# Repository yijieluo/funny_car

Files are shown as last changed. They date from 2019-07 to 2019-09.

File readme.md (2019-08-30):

### 2019/7/15

#### 引言
    1、这是用于rt-thread举办的智能战车DIY活动的一个项目.
    2、目标是设计一个两轮平衡小车，完成基本功能，平衡和遥控。如果有时间会增加树莓派做物体跟踪。   
    3、硬件搭建：采用大疆的m2006无刷电机搭配c610电调，采用6s航模锂电池供电（不加稳压模块），mcu选用stm32f407zgt6，imu模块选用gy-86，蓝牙hc-05作为遥控通信，选用us-100超声波模块用来避障。

#### 目前进度：
    1.已在正点原子探索者开发板上完成了：在rt-thread 4.0.0系统下，对两个电机的控制（基于can总线），读取gy-86的九轴数据（怀疑磁力计读数有问题，暂时姿态解算有问题），还有硬件定时器，软件定时器，LED控制等一下简单的功能。   
    2.pcb已经完成mcu最小系统，lm2576-5、asm1117-3.3稳压部分，can芯片tja1050电路，的设计。   
    3.电机支架和底板的机械图纸已设计好（同学帮忙设计的），已经送去加工了。

### 2019/8/28
#### 目前已基本完成要求功能，ps2遥控控制两轮平衡车较稳定的运行。

    1、硬件上，24v转5v，5转3.3v稳压电路，stm32f407zgt6最小系统与外围接口电路，pcb做了两版才成功。    
    2、软件上，完成了，姿态结算，数据滤波，串级pid 外环角度环，内环速度环，在线pid参数修改，串口配合山外调试助手在线看数据波形，ps2遥控控制等。

#### 还准备继续做的内容：
    1、减少一些全局变量的使用，用rtt的IPC来替代。    
    2、通过yaw角度或电机编码器，实现转向环 速度 的闭环控制。增加 前进 和 转向 的位置控制。（前面的都是速度控制）    
    3、增加树莓派做图像处理的一些工作。

#### [整理的博客](https://www.cnblogs.com/luoyijie/p/11433817.html)
#### [演示视频1](https://v.youku.com/v_show/id_XNDMzNzExODMyMA==.html) [演示视频2](https://v.youku.com/v_show/id_XNDMzNzExODMxNg==.html)

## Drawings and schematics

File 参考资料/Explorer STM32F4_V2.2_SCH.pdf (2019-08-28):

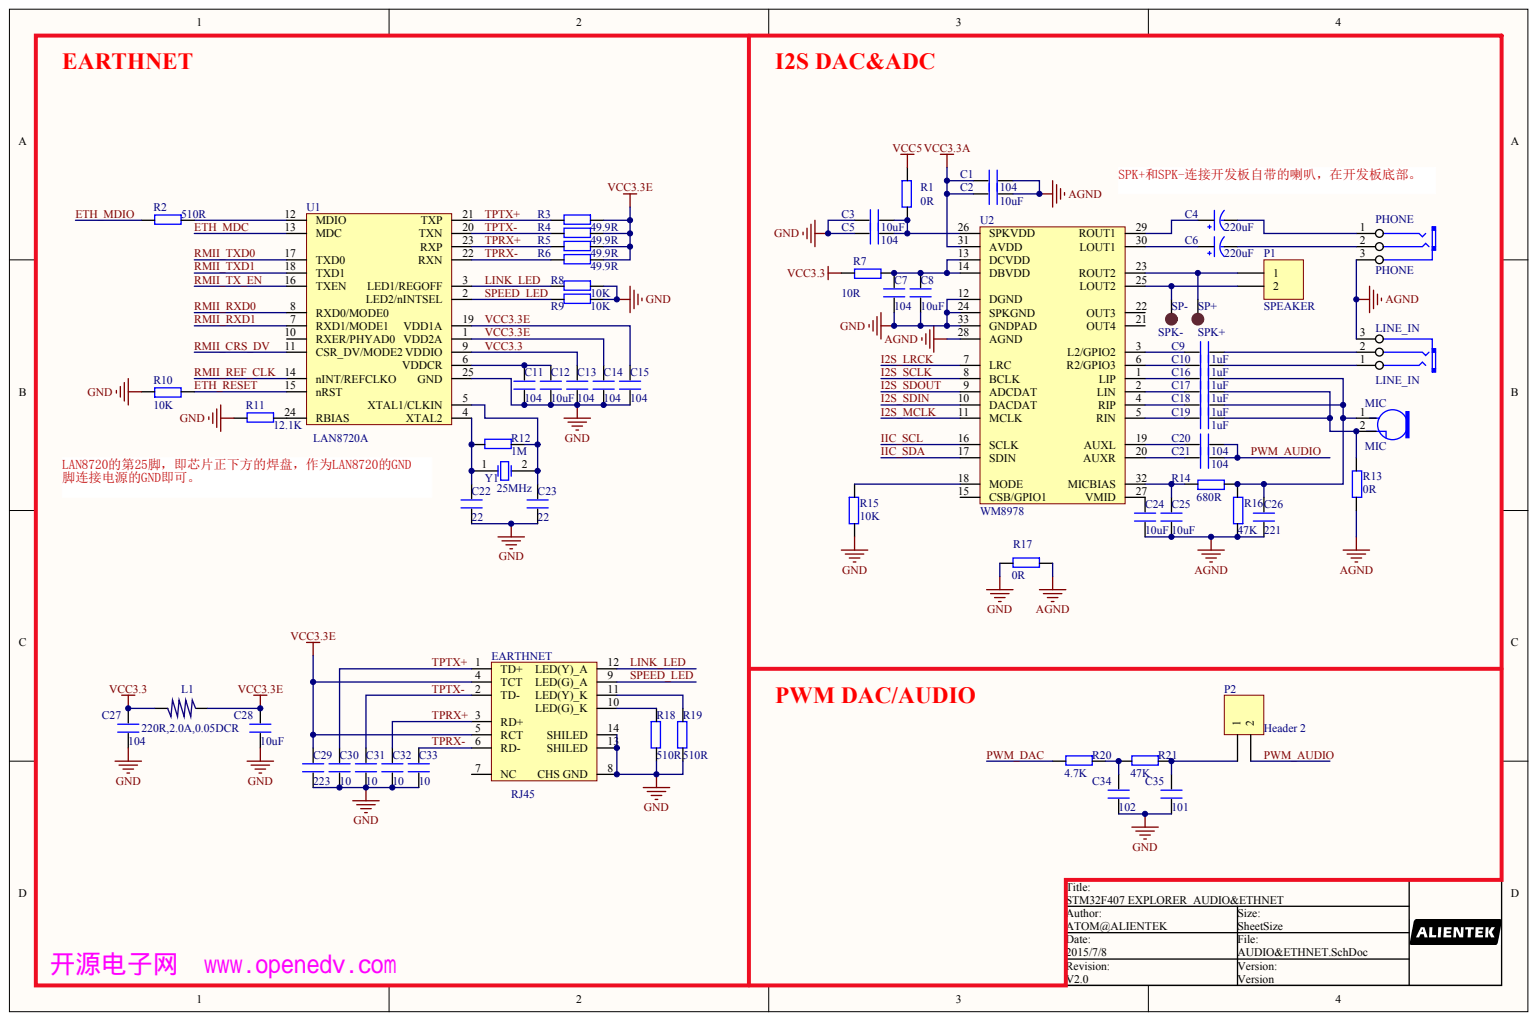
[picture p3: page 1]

SPK+和SPK-连接开发板自带的喇叭，在开发板底部。

TPTX- | | TD- 2

TPRX+ | | RD+ 3

RCT 5

Title: STM32F407 EXPLORER_AUDIO&ETHNET

Author: ATOM@ALIENTEK | Size: SheetSize

Date: 2015/7/8 | File: AUDIO&ETHNET.SchDoc

开源电子网 www.openedv.com

Revision: V2.0 | Version: Version

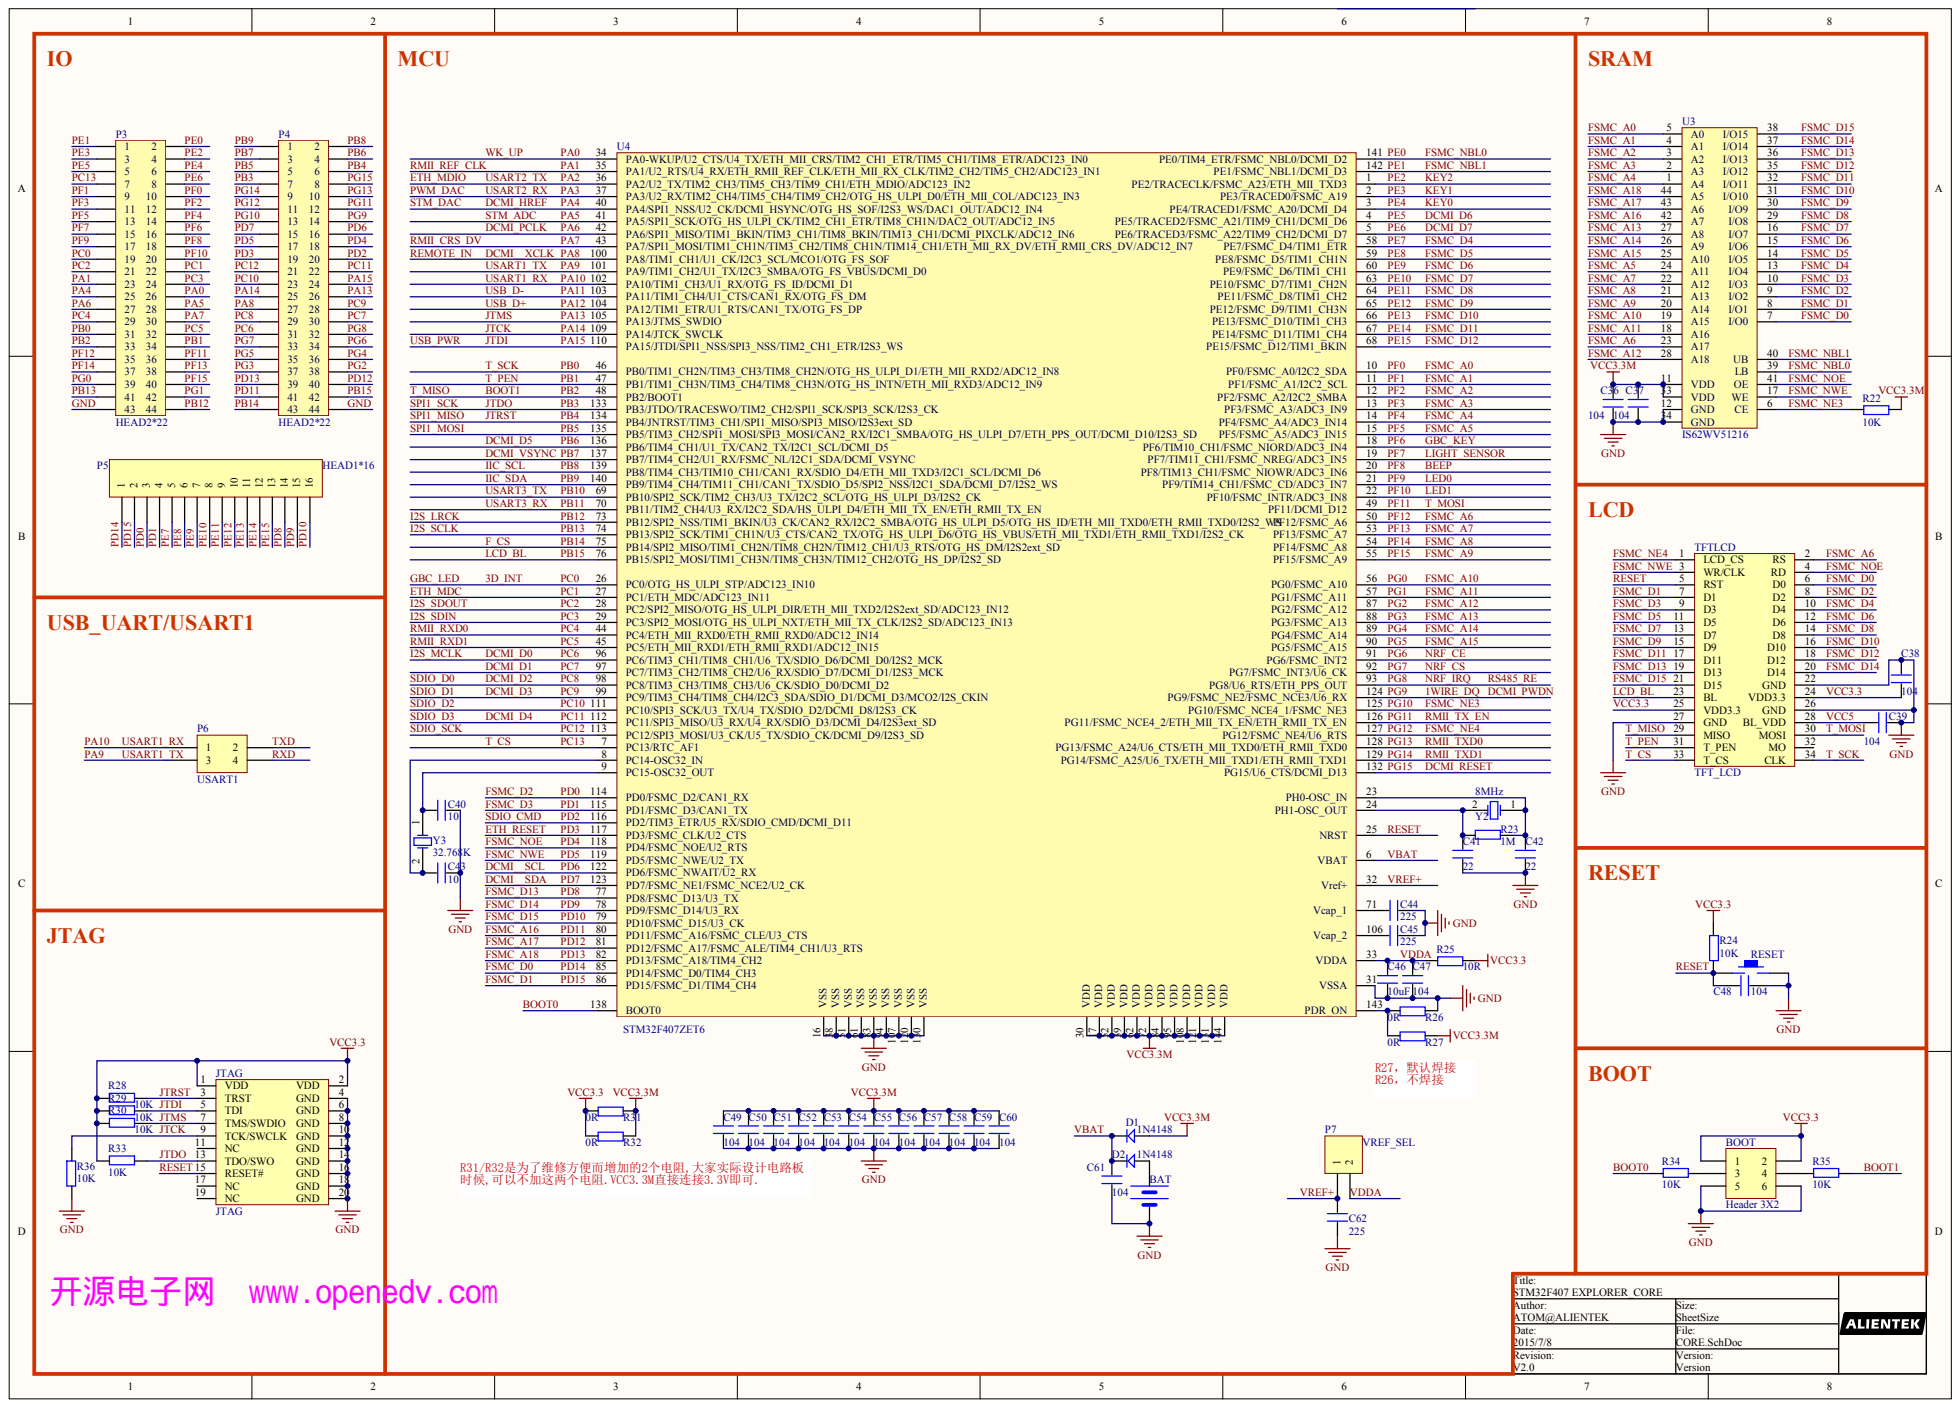
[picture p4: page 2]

开源电子网 www.openedv.com

Title: STM 32F407 EXPLORER_CORE

Author: ATOM @ALIENTEK | Size: SheetSize

Date: 2015/7/8 | File: CORE.SchDoc

Revisi on: V2.

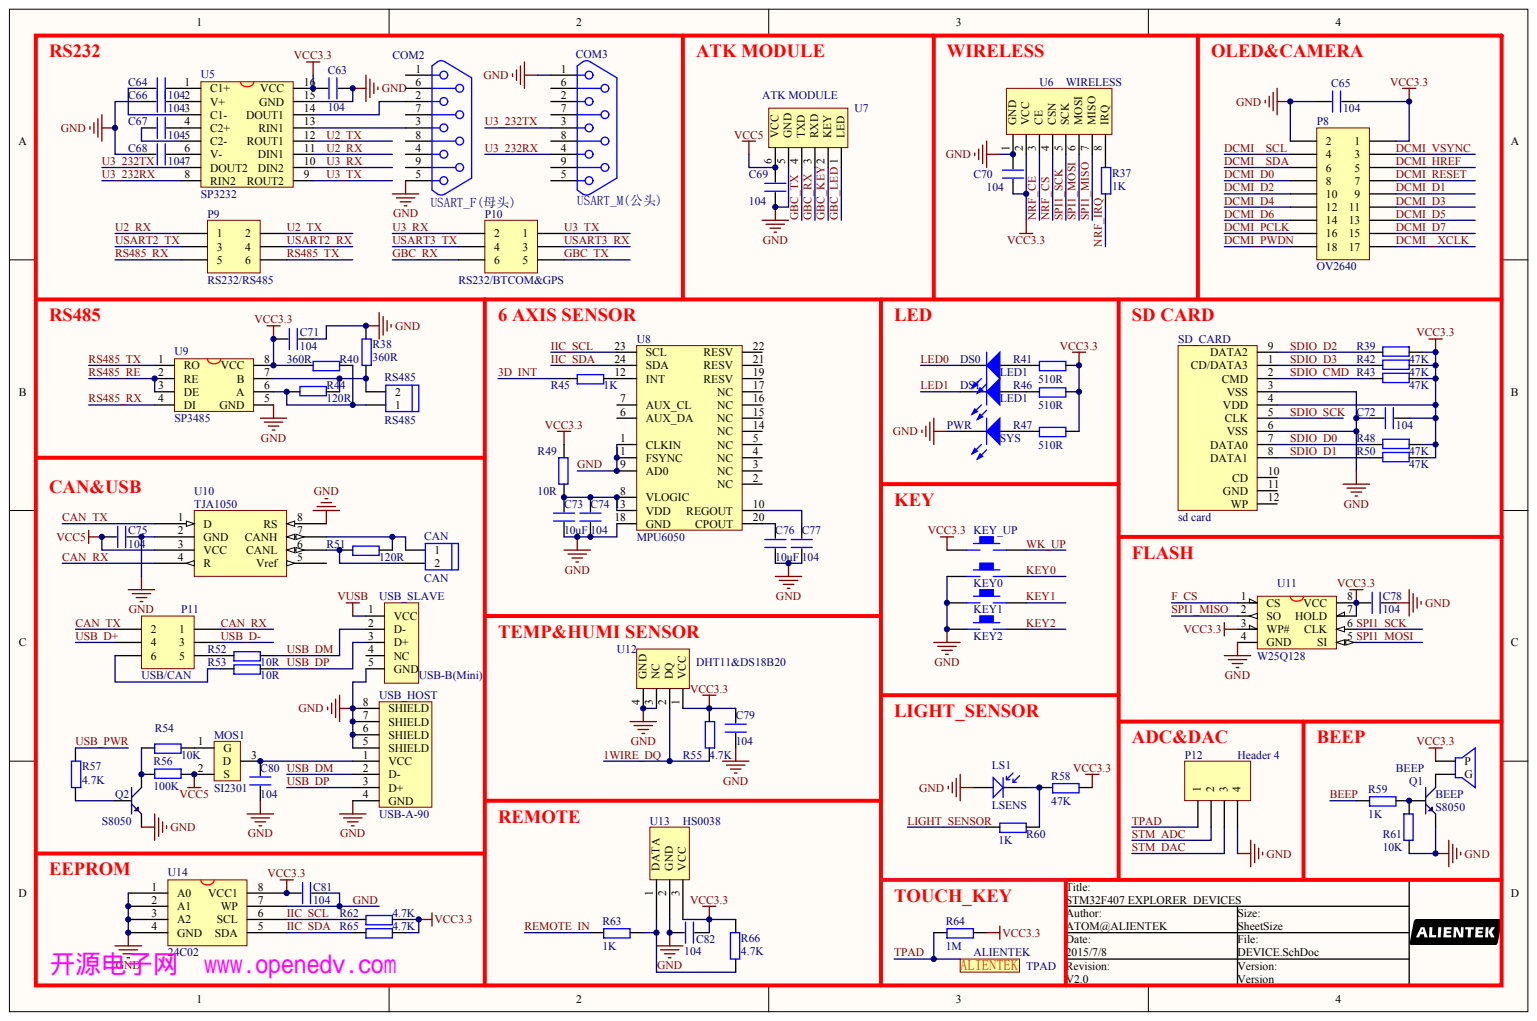
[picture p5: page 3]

LED 1 KEY 2 RXD 3 TXD 4

VCC 3

VCC 1 DQ 2 NC 3 GND 4

Author: ATOM@ALIENTEK | Size: SheetSize

Date: 2015/7/8 | File: DEVICE.SchDoc

开源电子网 www.openedv.com

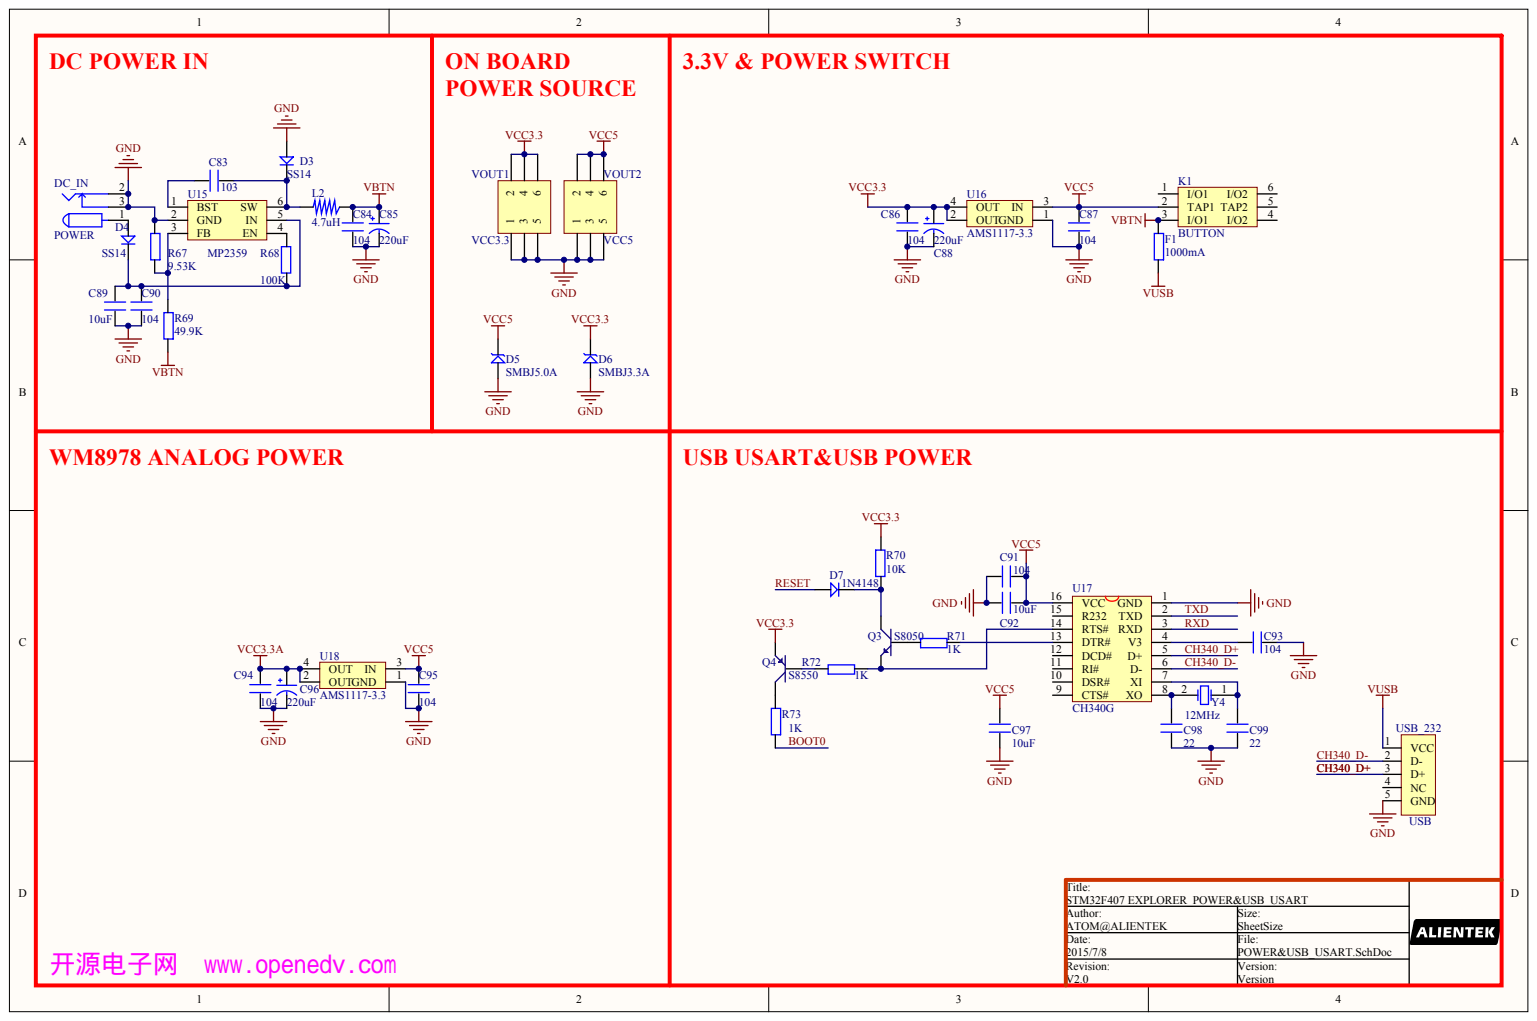
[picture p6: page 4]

Title: STM32F407 EXPLORER_POWER&USB_USART

Author: ATOM@ALIENTEK | Size: SheetSize

Date: 2015/7/8 | File: POWER&USB_USART.SchDoc

开源电子网 www.openedv.com

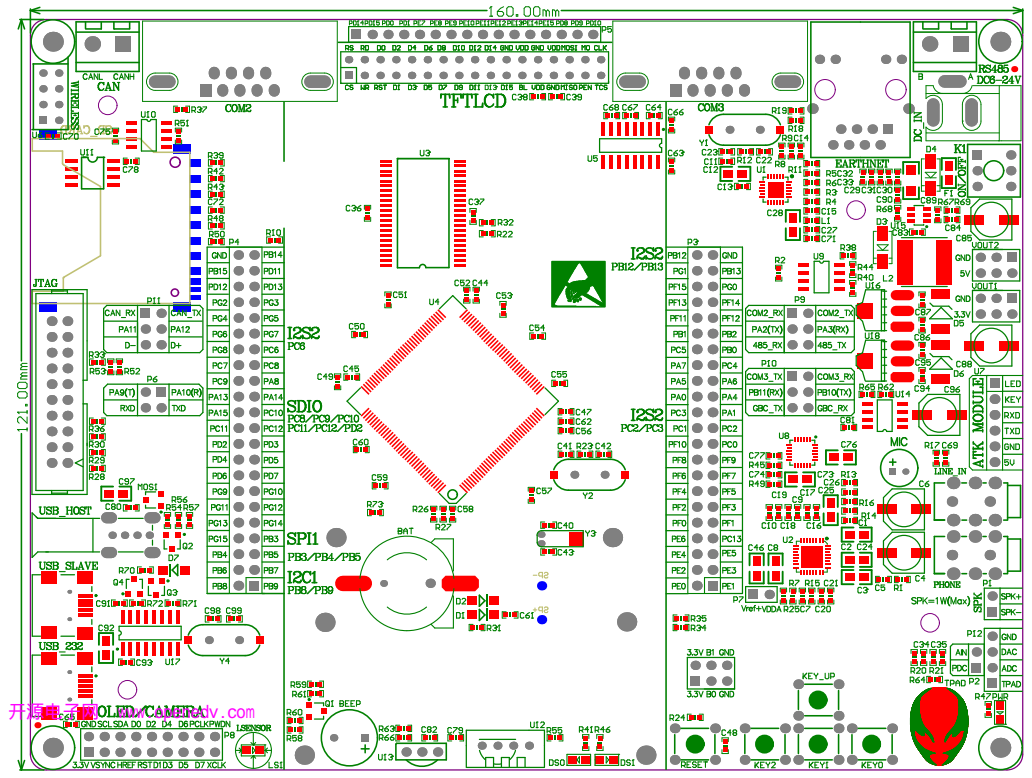
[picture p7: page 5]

开源电子网 www.openedv.com

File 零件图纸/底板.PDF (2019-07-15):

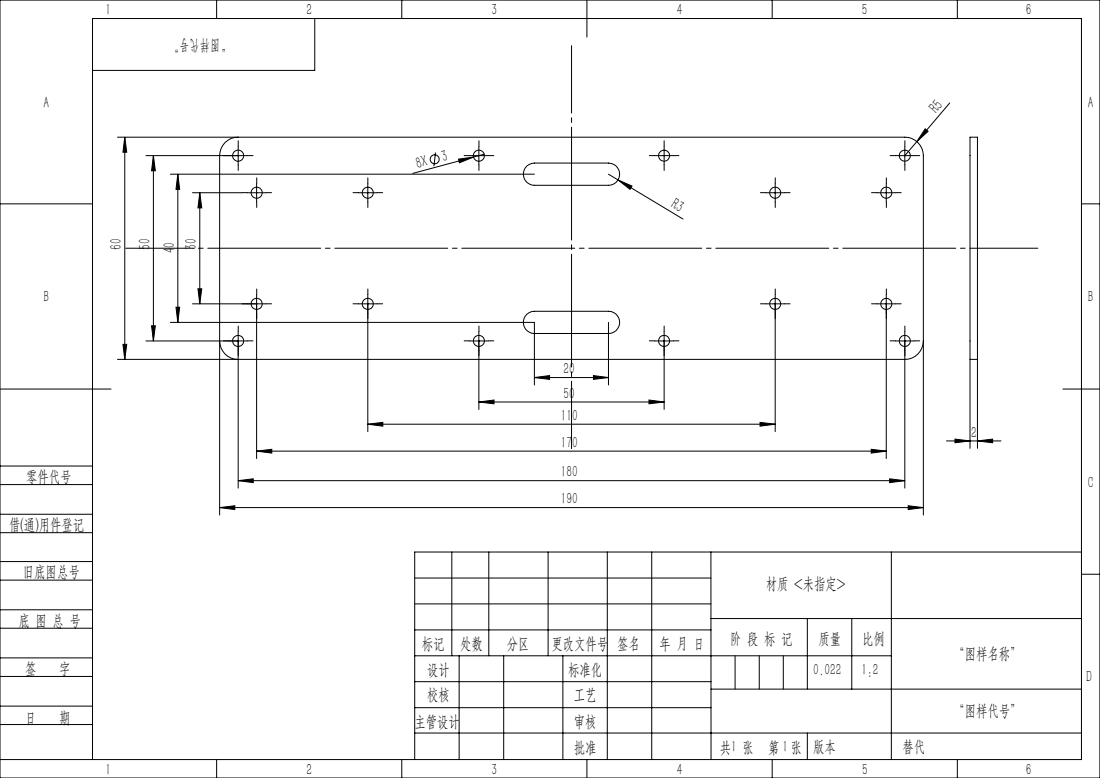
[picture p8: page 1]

材质 <未指定>

阶 段 标 记 | 质量 | 比例 | “图样名称”

标记 | 处数 | 分区 | 更改文件号 | 签名 | 年 月 日

“图样代号”

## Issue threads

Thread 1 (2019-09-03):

下载后编译提示没有stm32_rom.sct文件

wangxiufeng1104, 2019-09-03:
**.\build\rtthread-stm32f4xx.axf: error: L6031U: Could not open scatter description file .\stm32_rom.sct: No such file or directory**

iamluoyijie, 2019-09-03:
上传的时候把一些配置文件删了，我本地编译没问题，我明天上午看一下

iamluoyijie, 2019-09-04:
已经改好了，你可以试一下

wangxiufeng1104, 2019-09-04:
编译通过了

Closed 2019-09-05.

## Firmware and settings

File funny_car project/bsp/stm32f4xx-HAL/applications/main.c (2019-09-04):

#include <rtthread.h>
#include <board.h>
#include "can_app.h"
#include "timer_app.h"
#include "gy-86.h"
#include "imu.h"
#include "pid.h"
#include "motor.h"
#include "key.h"
#include "led.h"
#include "ps2.h"

struct imu_data imu;
rt_device_t can_dev = RT_NULL;
rt_device_t uart2_dev = RT_NULL;
rt_timer_t timer1;
float pitch,roll,yaw;
float roll_offset = 0;
float roll_target;
float rotation;
extern moto_measure_t moto_chassis[2];

int main(void)
{
		/*can设备初始化*/
		can_dev = rt_device_find(CAN1_DEVICE_NAME);
		if (!can_dev)
		{
				rt_kprintf("find %s failed!\n", CAN1_DEVICE_NAME);
				return RT_ERROR;
		}
		rt_device_open(can_dev, (RT_DEVICE_OFLAG_RDWR | RT_DEVICE_FLAG_INT_RX | RT_DEVICE_FLAG_INT_TX));
		if(rt_device_control(can_dev, RT_CAN_CMD_SET_BAUD, (void *)CAN1MBaud) != RT_EOK)
		{
				rt_kprintf("config %s failed!\n", CAN1_DEVICE_NAME);
		}
		rt_device_set_rx_indicate(can_dev, can1_receive);//设置接收回调函数
		
		//ps2遥控初始化
		ps2_init();
		
		//左右轮pid参数初始化
		pid_init();
		
		set_moto_current(can_dev,0,0);
		rt_thread_mdelay(1000);
		
		/*传感器GY-86初始化*/
		gy86_init();
		
		mpu6050_get_gyroscope(&imu);
		mpu6050_get_accelerometer(&imu);
		hmc5883l_get_magnetic(&imu);
		
		MahonyAHRSupdate(imu.gx/2000.0,imu.gy/2000.0,imu.gz/2000.0,imu.ax,imu.ay,imu.az,imu.mx,imu.my,imu.mz,&pitch,&roll,&yaw);
		
		roll_offset = roll;
		
		/*串口2初始化 蓝牙*/
		uart2_dev = rt_device_find("uart2");
    if (!uart2_dev)
    {
        rt_kprintf("find %s failed!\n", "uart2");
        return RT_ERROR;
    }
		rt_device_open(uart2_dev, RT_DEVICE_FLAG_INT_RX);	
			
		/* 软定时器初始化 */
    /* 创建定时器 1  周期定时器 */
    timer1 = rt_timer_create("timer1", balance_control,
                             RT_NULL, 1,
                             RT_TIMER_FLAG_PERIODIC|RT_TIMER_FLAG_SOFT_TIMER);

    /* 启动定时器 1 */
    if (timer1 != RT_NULL) rt_timer_start(timer1);
		
		/* 按键线程 */
		key_init();
		
		/* LED状态显示线程 */
		led_init();
		
		/* 电机电流保护线程 */ //pcb设计电流只有8A左右，电机全速电流是10A。
		motor_init();
		
		//因为这些线程初始化，顺序需要注意一下，用EXPORT宏不知道如何处理顺序

		/*main线程 一直更新imu数据*/
		while(1)
		{
			mpu6050_get_gyroscope(&imu);
			mpu6050_get_accelerometer(&imu);
			hmc5883l_get_magnetic(&imu);
			rt_thread_delay(1);
		}
}
//	float waveform[3] = {0};
//	waveform[0] = -rmp_target;
//	waveform[1] = moto_chassis[0].speed_rpm;
//	waveform[2] = moto_chassis[1].speed_rpm;
//	send_waveform_fomate(waveform, sizeof(waveform));	

//		/*硬件定时器初始化*/
//		hw_dev = rt_device_find(HWTIMER_DEV_NAME);
//		if (hw_dev == RT_NULL)
//    {
//        rt_kprintf("can't find %s device!\n", HWTIMER_DEV_NAME);
//        //return RT_ERROR;
//    }
//		ret = rt_device_open(hw_dev, RT_DEVICE_OFLAG_RDWR);
//		if (ret != RT_EOK)
//    {
//        rt_kprintf("open %s device failed!\n", HWTIMER_DEV_NAME);
//        return ret;
//    }
//		if(rt_device_set_rx_indicate(hw_dev, balance_control) != RT_EOK)
//		{
//				rt_kprintf("set_rx_indicate failed!\n");
//		}
//		rt_hwtimer_mode_t mode = HWTIMER_MODE_PERIOD;
//    ret = rt_device_control(hw_dev, HWTIMER_CTRL_MODE_SET, &mode);
//    if (ret != RT_EOK)
//    {
//        rt_kprintf("set mode failed! ret is :%d\n", ret);
//        return ret;
//    }
//		rt_hwtimerval_t timeout_s = {0,1000};//1ms
//		if (rt_device_write(hw_dev, 0, &timeout_s, sizeof(timeout_s)) != sizeof(timeout_s))
//    {
//        rt_kprintf("set timeout value failed\n");
//        return RT_ERROR;
//    }

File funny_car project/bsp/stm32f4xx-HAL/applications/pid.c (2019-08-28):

#include "pid.h"
#include "stm32f4xx.h"

#define ABS(x)		((x>0)? x: -x) 

//PID_TypeDef pid_pitch,pid_pithch_speed,pid_roll,pid_roll_speed,pid_yaw_speed;

/*参数初始化--------------------------------------------------------------*/
static void pid_param_init(
	PID_TypeDef * pid, 
	PID_ID   id,
	float maxout,
	float intergral_limit,
	float deadband,
	float period,
	float  max_err,
	float  target,

	float 	kp, 
	float 	ki, 
	float 	kd)
{
	pid->id = id;		
	
	pid->ControlPeriod = period;             //没用到
	pid->DeadBand = deadband;
	pid->IntegralLimit = intergral_limit;
	pid->MaxOutput = maxout;
	pid->Max_Err = max_err;
	pid->target = target;
	
	pid->kp = kp;
	pid->ki = ki;
	pid->kd = kd;
	
	pid->output = 0;
}

/*中途更改参数设定--------------------------------------------------------------*/
static void pid_reset(PID_TypeDef * pid, float kp, float ki, float kd)
{
	pid->kp = kp;
	pid->ki = ki;
	pid->kd = kd;
}

/*pid计算-----------------------------------------------------------------------*/
static float pid_calculate(PID_TypeDef* pid, float measure, float target)
{
	pid->measure = measure;
 	pid->target = target;
	pid->last_err  = pid->err;
	pid->last_output = pid->output;
	
	pid->err = pid->target - pid->measure;
	
	//是否进入死区
	if((ABS(pid->err) > pid->DeadBand))
	{
		pid->pout = pid->kp * pid->err;
		pid->iout += (pid->ki * pid->err);
		pid->dout =  pid->kd * (pid->err - pid->last_err); 
		
		//积分是否超出限制
		if(pid->iout > pid->IntegralLimit)
			pid->iout = pid->IntegralLimit;
		if(pid->iout < - pid->IntegralLimit)
			pid->iout = - pid->IntegralLimit;
		
		//pid输出和
		pid->output = pid->pout + pid->iout + pid->dout;
		
		if(pid->output>pid->MaxOutput)         
		{
			pid->output = pid->MaxOutput;
		}
		if(pid->output < -(pid->MaxOutput))
		{
			pid->output = -(pid->MaxOutput);
		}
	}
	return pid->output;
}

PID_TypeDef motor_pid[6];//左轮速度环，右轮速度环，左轮角度环，右轮角度环 左轮转向环 右轮转向环
void pid_init()
{
	//left wheel pid init
	motor_pid[0].f_param_init = pid_param_init;
	motor_pid[0].f_pid_reset = pid_reset;
	motor_pid[0].f_cal_pid = pid_calculate;	
	motor_pid[0].f_param_init(&motor_pid[0],PID_Speed,10000,9000,10,0,8000,0,7.5f,0.2f,6.2f);
	
	//right wheel pid init
	motor_pid[1].f_param_init = pid_param_init;
	motor_pid[1].f_pid_reset = pid_reset;
	motor_pid[1].f_cal_pid = pid_calculate;
	motor_pid[1].f_param_init(&motor_pid[1],PID_Speed,10000,9000,10,0,8000,0,7.5f,0.2f,6.2f);
	
	motor_pid[2].f_param_init = pid_param_init;
	motor_pid[2].f_pid_reset = pid_reset;
	motor_pid[2].f_cal_pid = pid_calculate;
	motor_pid[2].f_param_init(&motor_pid[2],PID_Position,7000,7000,0,0,60,0,560,70,130);
	
	motor_pid[3].f_param_init = pid_param_init;
	motor_pid[3].f_pid_reset = pid_reset;
	motor_pid[3].f_cal_pid = pid_calculate;
	motor_pid[3].f_param_init(&motor_pid[3],PID_Position,7000,7000,0,0,60,0,560,70,130);
}
//struct _PID_TypeDef *pid,PID_ID id,uint16_t maxOutput,uint16_t integralLimit,float deadband,uint16_t controlPeriod,int16_t max_err,int16_t  target,
//				   float kp,
//				   float ki,
//				   float kd

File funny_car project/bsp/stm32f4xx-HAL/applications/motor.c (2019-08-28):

#include "motor.h"
#include "can_app.h"

#define THREAD_PRIORITY             16
#define THREAD_STACK_SIZE           256
#define THREAD_TIMESLICE            1

#define ABS(x)		((x>0)? x: -x) 
static rt_thread_t      tid_motor      =   RT_NULL;


extern moto_measure_t moto_chassis[2];
extern rt_device_t can_dev;
extern rt_timer_t timer1;

#define SPEED_LIMIT 6800
static void motor_thread_entry(void *param) //电机电流保护线程
{
		while(1)
		{
				if(ABS(moto_chassis[0].speed_rpm) > SPEED_LIMIT || ABS(moto_chassis[1].speed_rpm) > SPEED_LIMIT)
				{
						rt_thread_mdelay(1000);
						if(ABS(moto_chassis[0].speed_rpm) > SPEED_LIMIT || ABS(moto_chassis[1].speed_rpm) > SPEED_LIMIT)
						{
								set_moto_current(can_dev, 0, 0);
								rt_timer_stop(timer1);
								break;
						}
				}
				rt_thread_mdelay(100);
		}
}

int motor_init(void)
{
			tid_motor = rt_thread_create("motor",
                          motor_thread_entry, RT_NULL,
                          THREAD_STACK_SIZE,
                          THREAD_PRIORITY, THREAD_TIMESLICE);

			if (tid_motor != RT_NULL)
			{
					rt_thread_startup(tid_motor);
			}
			else
			{
					rt_kprintf("Can't create thread for motor");
					return -RT_ENOSYS;
			} 
			return RT_EOK;
}

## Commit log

2019-08-30 修改了下readme的排版
2019-08-30 修改一下readme的排版
2019-09-04 add file stm32_rom.sct
    [Sheet1.SchDoc]
